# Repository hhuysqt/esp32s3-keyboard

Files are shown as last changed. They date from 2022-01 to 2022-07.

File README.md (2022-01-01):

# Thinkpad USB/BLE keyboard based on ESP32S3

This USB/BLE keyboard controller is built upon ESP32S3 (the ESP32S3-WROOM-1 module), which has hardware USB & BLE peripherals. It can support multiple Thinkpad laptop keyboards, if not limited to all sorts of matrix keyboards. The following functions are supported:

- Keyboard & LED;
- Mouse (trackpoint);
- Fn consumer/multimedia keys;
- USB & BLE connection;
- "Low-power": around 6-day BLE connection on a 1500mAh battery;

Tested on T440/T470/E430/E530/E580.

- E580 keyboard with 3D printed case:
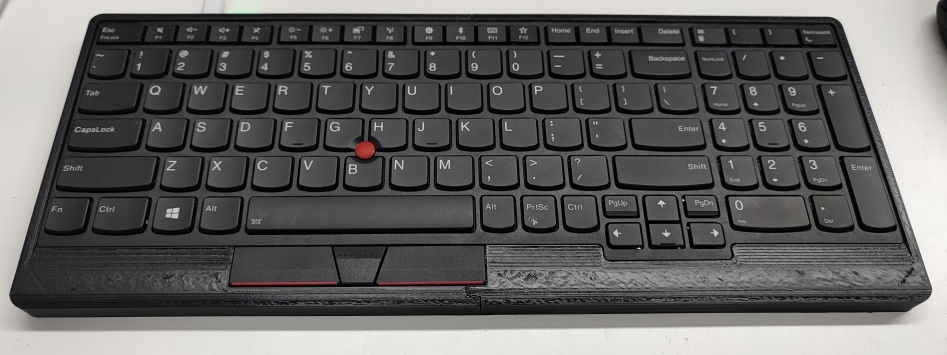
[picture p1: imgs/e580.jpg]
E580


- T470/T480 keyboard:
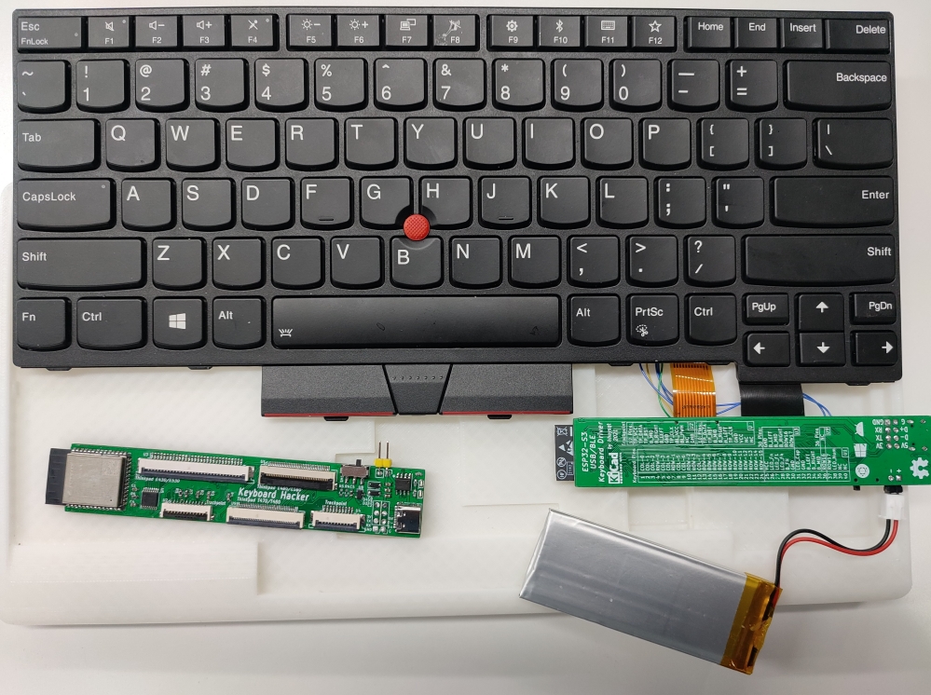
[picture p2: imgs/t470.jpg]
T470


The BLE and USB driver is mainly modified from:
- [ble_hid_device_demo](https://github.com/espressif/esp-idf/tree/master/examples/bluetooth/bluedroid/ble/ble_hid_device_demo) in `esp-idf`;
- [tinyusb hid](https://github.com/iot-components/tinyusb.git) component addon;

## Hardware

The Thinkpad keyboard modules are similar. Usually it contains a 32-40 pins FPC cable for keyboard matrix and LEDs, and a 10-12 FPC cable for trackpoint, mouse buttons and backlight. The keyboard matrix comprises 24 or 26 pins, where 8 of them are sense ports and the remaining drive ports. The trackpoint contains 3 input ports for mouse buttons, and a PS2 interface for mouse report. The following pinout is extracted from the [E580](https://badcaps.net/forum/attachment.php?attachmentid=215193&d=1593808132) schematic.

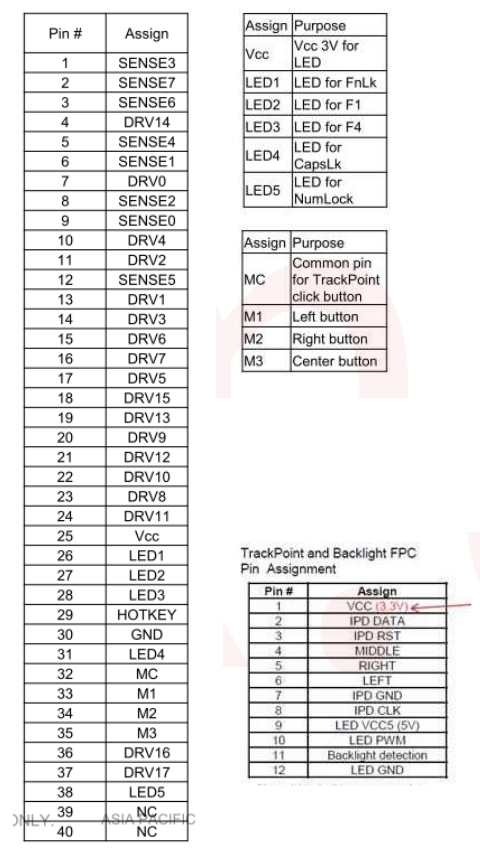
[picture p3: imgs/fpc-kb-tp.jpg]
Keyboard & trackpoint pinout


Although ESP32 has no PS2 interface, we notice that the slave-to-host timing of PS2 DATA pin is identical to the UART (1 start bit, 8 data bit, 1 odd parity, 1 stop bit). While by contrast the host-to-slave timing is NOT compatible, this only happens during initialization. Thereby this step requires bit-banging.

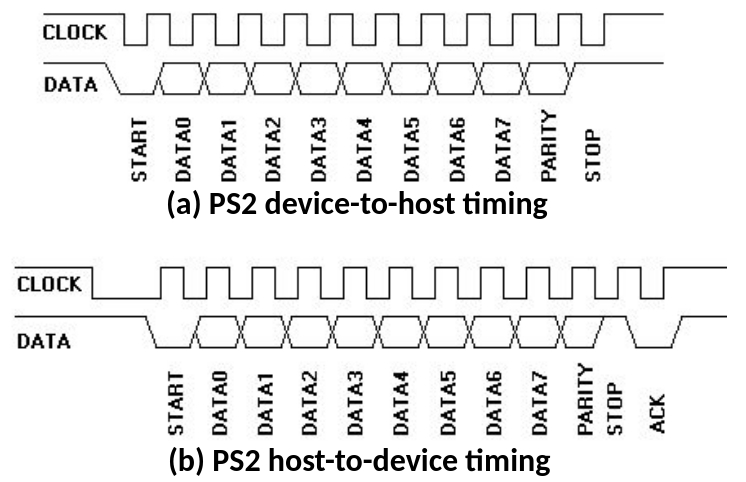
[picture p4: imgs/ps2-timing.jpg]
PS2 timing


The ESP32S3-WROOM-1 module has 36 GPIOs, among which should reserve the USB port (IO19/20), and the 32.768kHz external oscillator for low-power modem sleep (IO15/16). To fully drive the keyboard matrix, LEDs and PS2 trackpoint mouse, a 74HC138 is used to expand the poor IOs... See the [schematic](hardware/esp32_keyboard.pdf) for detail.
- Keyboard: 3 pins for column scanning with 74HC138, plus 18 pins for row sensing;
- Trackpoint: 3 pins (RST, CLK, DATA);
- LEDs: 4 pins (FnLock, CapLk, NumLk, F1, mux with the UART0), plus 1 pin for the keyboard backlight;
- Hotkey/Fn: 1 pin;
- 5V wake up: 1 pin;
- Download Pin: IO0, connected to the middle button;

## Build & Run

We build with the normal esp-idf project workflow on Linux:

```bash
idf.py set-target esp32s3
idf.py build
```

To update the firmware, we should first power off the board, hold the middle button, plug in the USB cable, and then we can release the button. The USB-CDC hardware in the ESP32S3 should launch a `/dev/ttyACMx` on your computer, which can be used to flash the firmware:

``` bash
idf.py -p /dev/ttyACM0 flash
```

Finally, unplug the USB cable and power on the board.

## Power consumption

The ESP32 is known to be power hungry... We use a 1500mAH battery for the keyboard, and the original `ble_hid_device_demo` would take over 100mA without midification, which means a poor 15-hour battery life. For lower-power design, we should adopt the [BLE modem sleep with external 32kHz crystal under light sleep](https://github.com/espressif/esp-idf/issues/947#issuecomment-500312453), which claims an average ~2mA current with ~1000ms BLE connection interval. However, 1000ms (1Hz) interval is too long for real-time keyboard response, and we have to decrease it to around 50ms (20Hz) for normal use. Moreover, the trackpoint/mouse requires a even shorter period, which we set to 12.5ms (80Hz). With this backdrop, we develop a multi-stage power management as follow. This can be configured in [keyboard_pm.c](main/keyboard_pm.c).

| Charging | BLE Connect | Keyboard Scanning | Trackpoint | BLE Interval | Current | Duration |
|--|--|--|--|--|--|--|
| No | No | Slow | No | 1000ms | ~5mA | - |
| No | Yes | Slow | No | 1000ms | ~8mA | - |
| No | Yes | Slow | No | 400ms | 13mA | 120s |
| No | Yes | Fast | No | 50ms | 30mA | 240s |
| No | Yes | Fast | Yes (cannot sleep) | 12.5ms | 53mA | 120s |
| Yes | - | - | - | - | -500mA | - |

Note:
- The ESP32 light sleep would force turning off all the peripherals, which means that we will never receive trackpoint message at sleep. So the trackpoint forces no sleep.
- The USB 2.0 host could offer ~500mA current, which means that it takes 3 hours to charge the 1500mAh battery. This is quite a modest setting, and this is why we don't use a larger battery like 2500mAh.
- Backlight takes an additional 50mA.

Battery life estimation (1500mAh):
- 12 days if no BLE connection;
- ~6 days for normal use;

## TODO list

- Online configuration;
- `Fn` and `Left Ctrl` exchange;
- Multiple BLE cnnection;
- More keyboards, e.g. X220;
- More OS support, e.g. Mac;

## Reference

- [How to Make a USB Laptop Keyboard Controller](https://www.instructables.com/How-to-Make-a-USB-Laptop-Keyboard-Controller/)
- [Laptop Touchpad/Trackpoint Conversion to USB](https://www.hackster.io/frank-adams/laptop-touchpad-trackpoint-conversion-to-usb-d70519)
- [esp32 BLE bridge for mouse and keyboard](https://github.com/asterics/esp32_mouse_keyboard)
- [HID scancodes](https://deskthority.net/wiki/Scancode#cite_ref-xmeta_13-0)
- [Trackpoint hardware](https://deskthority.net/wiki/TrackPoint_Hardware)

Thinkpad schematics:
- [T440](https://drive.google.com/file/d/1L-NCRwoP0IHYmOoxbS2U5ZWHYhyHf4xC/view)
- [T470](https://www.badcaps.net/forum/attachment.php?attachmentid=201515&d=1571565529)
- [E430/E530](https://drive.google.com/file/d/0B6IqcVTk0jpYV0xfMUdOay1uWlE/view?resourcekey=0-oamnnXMgSrohielovUks4A)
- [E580](https://badcaps.net/forum/attachment.php?attachmentid=215193&d=1593808132)

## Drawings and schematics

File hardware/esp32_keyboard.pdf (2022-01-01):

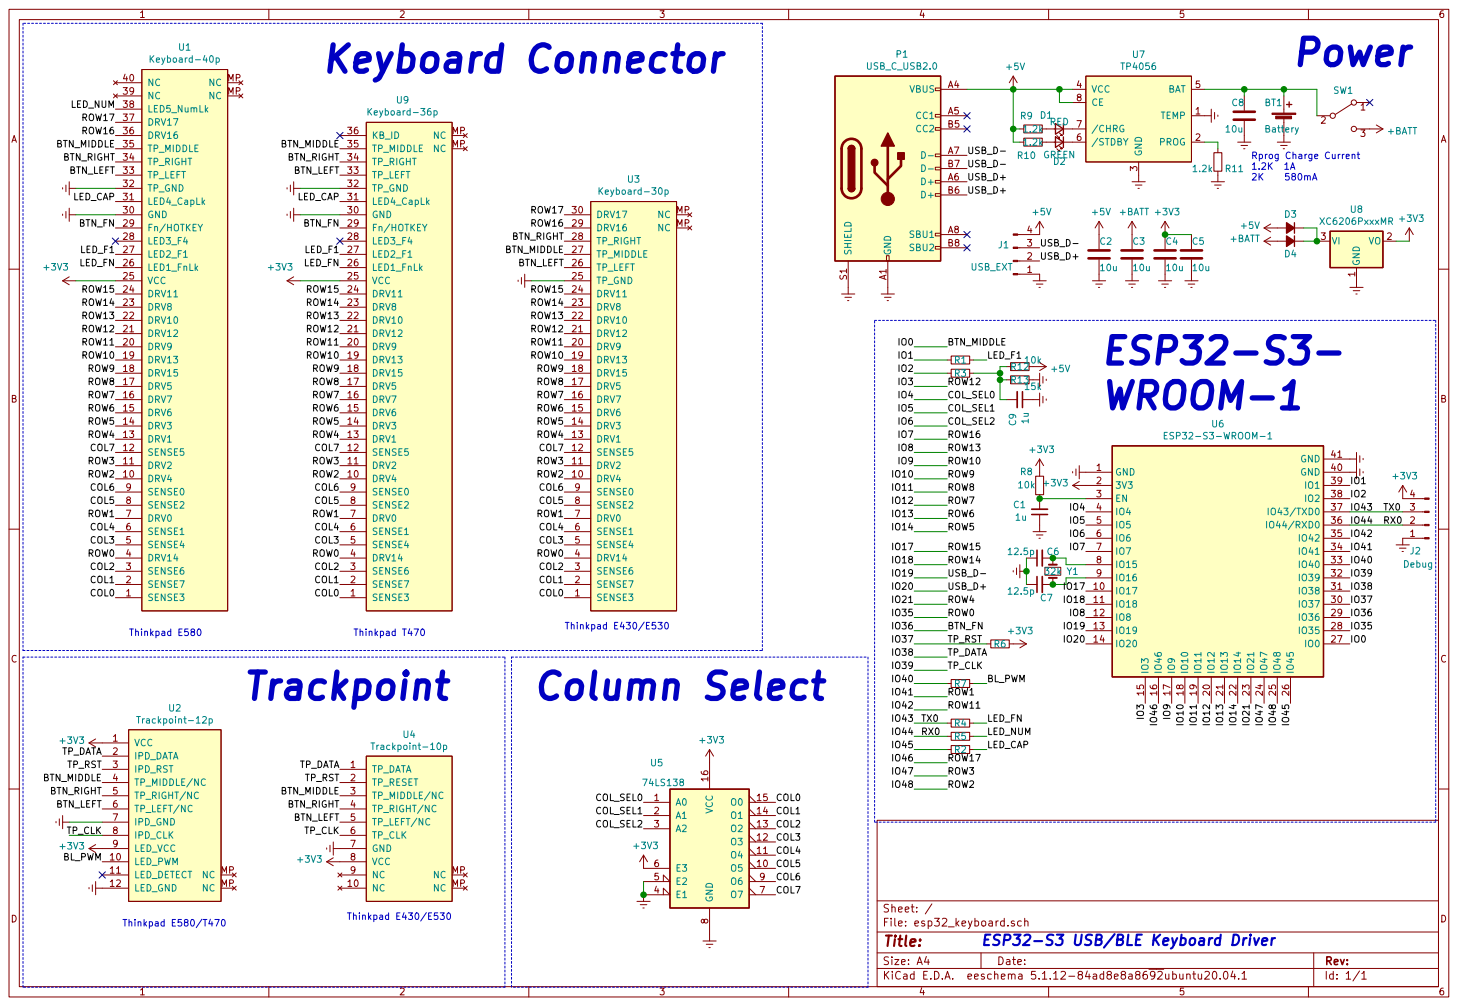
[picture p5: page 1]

BTN_LEFT ROW15 ROW14 ROW13 ROW12 ROW11 ROW10 ROW9
2K 580mA ESP32-S3 USB/BLE Keyboard Driver

1 VO 2 VI 3 U8 XC6206PxxxMR GND A1 VBUS A4 CC1 A5 D+ A6 D- A7 SBU1 A8 CC2 B5 D+ B6 D- B7 SBU2 B8 SHIELD S1 P1 USB_C_USB2.0 R3 R7 +3V3 C91u R5 R2

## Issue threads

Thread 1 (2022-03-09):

关注 X220 键盘适配

M69W, 2022-03-09:
目前使用 X220 键盘，手感略好。
大佬们，有任何进展或 建议，
不妨在这里，我们一起讨论交流？

hhuysqt, 2022-03-09:
x220的板对板接口，集合了矩阵键盘和小红点ps2接口，这份代码应该都能驱动起来，按理说加一个转接板就好了。

GaloisTsai, 2022-03-23:
> 目前使用 X220 键盘，手感略好。 大佬们，有任何进展或 建议， 不妨在这里，我们一起讨论交流？

[淘宝xy3dg12的小店](https://xy3dg12.taobao.com/)2年前曾经做过x220键盘的三模驱动板但不幸的是已停产，[Hearttolin工作室](https://jiushuma.taobao.com/)也有拿STM32做的有线版目前还在售，两者我都有

M69W, 2022-03-24:
> > 目前使用 X220 键盘，手感略好。 大佬们，有任何进展或 建议， 不妨在这里，我们一起讨论交流？
>
> [淘宝xy3dg12的小店](https://xy3dg12.taobao.com/)2年前曾经做过x220键盘的三模驱动板但不幸的是已停产，[Hearttolin工作室](https://jiushuma.taobao.com/)也有拿STM32做的有线版目前还在售，两者我都有

他们的 2 模、3模，我也要。
这里大佬的，我也买了。

不太想为了键盘体验而去买几千元整机。

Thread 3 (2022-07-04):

准备搞个X200的，请教作者几个问题

hktklsh, 2022-07-04:
首先感谢作者的分享，家里有个x200的闲置键盘，准备搞一搞，有几个问题想请教下作者：
1、由于鼠标中键没有对应引脚，把power按键接IO0可行不，或者您有什么更好的建议吗？
2、keymap如何映射，每按一个键，调试口会输出按键map信息吗？
3、x200键盘上没有指示灯，需要单独接led，对于驱动指示灯的引脚，我应该接led的正还是负？

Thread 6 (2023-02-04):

Any way to buy the board outside China?

diyprojectz, 2023-02-04:
Hello,

Is there any way I can order it? I am outside China.

Thank you

你好，

有什么办法可以订购吗？ 我在中国境外。

谢谢

hhuysqt, 2023-02-06:
Hi, I've updated the kicad PCB project along with gerber files, so that you can make the PCB on your own. Sorry but I'm no longer selling the board since it is just a hobby project :-D

antonba, 2025-09-17:
What is a good company to order the board from that can also solder all components on it (e.g. ESP32, FPC connectors, USB connetors)? Which company did you use?

Closed 2023-02-06.

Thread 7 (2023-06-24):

fpc插座要用怎样的？

lantianning, 2023-06-24:
我按照电路图要求先找了一块T470键盘，然后找了2块fpc插座，一个是36P 0.5mm间距，另外一个是12P 1mm间距的，结果把键盘插上去，发现卡不住，总觉得差哪里？不知道插座的厚度有没有要求？究竟这个fpc插座的规格？还有什么细节要求？求大神指导。

hhuysqt, 2023-06-25:
卡扣也占地方的，我试验用40pin 0.5的刚好安装，前后预留两个空脚。12pin的要带卡扣的，我买了这个能用，具体型号不清楚。
【淘宝】https://m.tb.cn/h.UA6Ymtd?tk=IRE0dINBQKo CZ3457 「FPC连接器12P翻盖式下接1.0MM间距 12PIN带定位卡扣软排线FFC插座」
点击链接直接打开 或者 淘宝搜索直接打开

lantianning, 2023-07-04:
谢谢你，我先记录了

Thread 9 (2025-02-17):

Do you plan on makeing 220 or 60 series version?

Onshumikan, 2025-02-17:
Hi, I have a broken x61, and wanted to make a usb & Bluetooth keyboard from it.
After searching around, I found your project.
Since, I saw other issues talking about x220? (sorry if im wrong, i could only read the "x220") , 60 series keyboard connector(AA01B-S040VA1) is simillar to x220s and you had it in your TO DO list, i wondered if you were already working on it.

If not, i was thinking of trying to make one my self, and i wanted an advice on how to make it.

i found several people who made an usb controller but not one with a bluetooth function.
https://github.com/xing2387/esp32s3_tpkb
https://github.com/thedalles77/USB_Laptop_Keyboard_Controller/tree/master/Example_Keyboards/Pico_T61_Keyboard

thanks to their work, they made a list of pinout for the 60 series keyboard connector(AA01B-S040VA1).
which, made me wonder if i can make one by modifying your design to match the connector pins.

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

however, im not that sure about which pins match which GPIOS.

can you help me out with it?

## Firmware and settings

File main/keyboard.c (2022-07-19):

/**
 * This file is part of esp32s3-keyboard.
 *
 * Copyright (C) 2020-2021 Yuquan He <heyuquan20b at ict dot ac dot cn> 
 * (Institute of Computing Technology, Chinese Academy of Sciences)
 *
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
 * You should have received a copy of the GNU General Public License
 * along with esp32s3-keyboard. If not, see <http://www.gnu.org/licenses/>.
 */

/**
 * Driver for Thinkpad keyboard & trackpad
 * USB & BLE interface.
 */

#include <stdio.h>
#include <string.h>
#include "freertos/FreeRTOS.h"
#include "freertos/task.h"
#include "sdkconfig.h"
#include "esp_log.h"

#include "driver/gpio.h"
#include "driver/uart.h"

#include "tusb.h"
#include "tusb_hid.h"
#include "tinyusb.h"
#include "esp_hidd_prf_api.h"
#include "esp_gap_ble_api.h"

#include "keymap.h"

#include "esp_err.h"
#include "esp_pm.h"
#include "esp_sleep.h"
#include "esp_timer.h"

#include <sys/fcntl.h>
#include <sys/errno.h>
#include <sys/unistd.h>
#include <sys/select.h>

#include "pin_cfg.h"
#include "keyboard_pm.h"

/****************************************************************
 * 
 *  Private Definition
 * 
 ****************************************************************/

// #define USE_FN_TRACKPOINT_PAN
#define SCALE_TRACKPOINT_SPEED
#define MOUSE_SCALE_MIN 1

/****************************************************************
 * 
 *  Private Varibles
 * 
 ****************************************************************/

static bool is_init_finish = false;
static bool is_fn_locked = 0;

// keyboard pin array
static uint rowscan_pins[18] = {
  KB_ROW_0, KB_ROW_1, KB_ROW_2, KB_ROW_3, KB_ROW_4, KB_ROW_5, KB_ROW_6, KB_ROW_7,
  KB_ROW_8, KB_ROW_9, KB_ROW_10, KB_ROW_11, KB_ROW_12, KB_ROW_13, KB_ROW_14, KB_ROW_15,
  KB_ROW_16, KB_ROW_17,
};

// UART1 fd for select()
static int uart1_fd = -1;

static uint wakeup_time = 0;
static const uint wakeup_period_us = 15000000;

// backlight duration
static const int MAX_BACKLIGHT_ON_US = 10*60*1000000;

static const char *TAG = "kb-task";

/****************************************************************
 * 
 *  Public Varibles
 * 
 ****************************************************************/

volatile bool is_usb_connected = false;
volatile bool is_backlight_on = false;
volatile int backlight_start_time;

// Manage LED state since Win10 won't report such info on BLE.
volatile bool is_caplk_on = false;
volatile bool is_numlk_on = false;

// bluetooth stuff
extern bool is_ble_connected;
extern esp_ble_conn_update_params_t ble_conn_param;
extern esp_pm_config_esp32s3_t esp_idf_pm_cfg;

/****************************************************************
 * 
 *  Private function prototypes
 * 
 ****************************************************************/

static void ps2_gpio_init(void);
static uint8_t ps2_read(void);
static void ps2_write_1(uint8_t ch);
static void ps2_write_2(uint8_t ch);

static void init_usb(void);
static void init_trackpad(void);
static void init_matrix_keyboard(void);

static void kb_set_column_scan(int n);
static void do_fnfunc(fn_function_t fncode);
static void led_task(void *arg);
static void poll_trackpoint(uint poll_ms);

/****************************************************************
 * 
 *  Callback override
 * 
 ****************************************************************/

// tinyusb callbacks for connection
void tud_mount_cb(void)
{
  is_usb_connected = true;
  printf("USB connected.\n");
  if (is_init_finish) {
    flush_power_state(PM_CHARGING);
  }
}

// tinyusb callbacks for disconnection
void tud_umount_cb(void)
{
  is_usb_connected = false;
  printf("USB disconnected\n");
}

void tud_suspend_cb(bool remote_wakeup_en)
{
  (void)remote_wakeup_en;
  is_usb_connected = false;
  // printf("USB suspended, %s\n");
  printf("%s(%s)\n", __func__, remote_wakeup_en ? "true" : "false");
}

void tud_resume_cb(void)
{
  is_usb_connected = true;
  printf("%s\n", __func__);
  if (is_init_finish) {
    flush_power_state(PM_CHARGING);
  }
}

void kb_led_cb(uint8_t kbd_leds)
{
  if (kbd_leds & KEYBOARD_LED_NUMLOCK) {
    LED_NUMLK_ON;
    is_numlk_on = true;
  } else {
    LED_NUMLK_OFF;
    is_numlk_on = false;
  }

  if (kbd_leds & KEYBOARD_LED_CAPSLOCK) {
    // Sometimes the GPIO may be reset on wake-up...
    // Manually init it again...
    GPIO_INIT_OUT_PULLUP(LED_CAPLK);
    LED_CAPLK_ON;
    is_caplk_on = true;
  } else {
    LED_CAPLK_OFF;
    is_caplk_on = false;
  }
}


/****************************************************************
 * 
 *  Private functions
 * 
 ****************************************************************/

/**
 * Initialize trackpad GPIO
 */
static void ps2_gpio_init(void)
{
  GPIO_INIT_OUT_PULLUP(PS2_CLK_PIN);
  GPIO_INIT_OUT_PULLUP(PS2_DATA_PIN);
  PS2_CLK_HIGH;
  PS2_DATA_HIGH;
}
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

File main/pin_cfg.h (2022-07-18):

/**
 * This file is part of esp32s3-keyboard.
 *
 * Copyright (C) 2020-2021 Yuquan He <heyuquan20b at ict dot ac dot cn> 
 * (Institute of Computing Technology, Chinese Academy of Sciences)
 *
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
 * You should have received a copy of the GNU General Public License
 * along with esp32s3-keyboard. If not, see <http://www.gnu.org/licenses/>.
 */

/**
 * Keyboard pin configuration
 */
#ifndef MY_PIN_CFG_H
#define MY_PIN_CFG_H

#include "sdkconfig.h"
#include "driver/gpio.h"


/****************************************************************
 * 
 *  GPIO allocation
 * 
 ****************************************************************/

// 8 column scan with 74HC138
#define KB_COLSEL_0   4
#define KB_COLSEL_1   5
#define KB_COLSEL_2   6

// 18 row scan
#define KB_ROW_0      35
#define KB_ROW_1      41
#define KB_ROW_2      48
#define KB_ROW_3      47
#define KB_ROW_4      21
#define KB_ROW_5      14
#define KB_ROW_6      13
#define KB_ROW_7      12
#define KB_ROW_8      11
#define KB_ROW_9      10
#define KB_ROW_10     9
#define KB_ROW_11     42
#define KB_ROW_12     3
#define KB_ROW_13     8
#define KB_ROW_14     18
#define KB_ROW_15     17
#define KB_ROW_16     7
#define KB_ROW_17     46

// Buttons
#define BUTTON_MIDDLE 0
#define BUTTON_FN     36

// LED
#define LED_CAPLK     45
#define LED_FNLK      43
#define LED_F1        1
#define LED_NUMLK     44
#define BACKLIGHT_PWM 40
// #define LED_F4        7

// Trackpad GPIO
#define PS2_CLK_PIN     39
#define PS2_DATA_PIN    38
#define PS2_RESET_PIN   37

// USB charging detection
#define CHARGING_PIN    2

#define BUTTON_MIDDLE_STATE gpio_get_level(BUTTON_MIDDLE)
#define BUTTON_FN_STATE     gpio_get_level(BUTTON_FN)

#define LED_CAPLK_ON    gpio_set_level(LED_CAPLK, 0)
#define LED_CAPLK_OFF   gpio_set_level(LED_CAPLK, 1)
#define LED_FNLK_ON     gpio_set_level(LED_FNLK, 0)
#define LED_FNLK_OFF    gpio_set_level(LED_FNLK, 1)
#define LED_F1_ON       gpio_set_level(LED_F1, 0)
#define LED_F1_OFF      gpio_set_level(LED_F1, 1)
#define LED_NUMLK_ON    gpio_set_level(LED_NUMLK, 0)
#define LED_NUMLK_OFF   gpio_set_level(LED_NUMLK, 1)
#define BACKLIGHT_ON    gpio_set_level(BACKLIGHT_PWM, 1)
#define BACKLIGHT_OFF   gpio_set_level(BACKLIGHT_PWM, 0)
// #define LED_F4_ON       gpio_set_level(LED_F4, 0)
// #define LED_F4_OFF      gpio_set_level(LED_F4, 1)

#define PS2_CLK_STATE   gpio_get_level(PS2_CLK_PIN)
#define PS2_CLK_OUTPUT  gpio_set_direction(PS2_CLK_PIN,  GPIO_MODE_OUTPUT)
#define PS2_CLK_INPUT   gpio_set_direction(PS2_CLK_PIN,  GPIO_MODE_INPUT)
#define PS2_CLK_LOW     gpio_set_level(PS2_CLK_PIN, 0)
#define PS2_CLK_HIGH    gpio_set_level(PS2_CLK_PIN, 1)
#define PS2_DATA_STATE  gpio_get_level(PS2_DATA_PIN)
#define PS2_DATA_OUTPUT gpio_set_direction(PS2_DATA_PIN, GPIO_MODE_OUTPUT)
#define PS2_DATA_INPUT  gpio_set_direction(PS2_DATA_PIN, GPIO_MODE_INPUT)
#define PS2_DATA_LOW    gpio_set_level(PS2_DATA_PIN, 0)
#define PS2_DATA_HIGH   gpio_set_level(PS2_DATA_PIN, 1)

#define CHARGING_STATE  gpio_get_level(CHARGING_PIN)

/****************************************************************
 * 
 *  Handy GPIO helpers
 * 
 ****************************************************************/

#define GPIO_INIT_IN_FLOATING(pinnum) \
  do { \
    gpio_reset_pin(pinnum); \
    gpio_set_direction(pinnum, GPIO_MODE_INPUT); \
    gpio_pullup_dis(pinnum); \
    gpio_pulldown_dis(pinnum); \
  } while(0)

#define GPIO_INIT_IN_PULLUP(pinnum) \
  do { \
    gpio_reset_pin(pinnum); \
    gpio_set_direction(pinnum, GPIO_MODE_INPUT); \
    gpio_pullup_en(pinnum); \
    gpio_pulldown_dis(pinnum); \
  } while(0)

#define GPIO_INIT_IN_PULLDOWN(pinnum) \
  do { \
    gpio_reset_pin(pinnum); \
    gpio_set_direction(pinnum, GPIO_MODE_INPUT); \
    gpio_pullup_dis(pinnum); \
    gpio_pulldown_en(pinnum); \
  } while(0)

#define GPIO_SET_PULLUP(pinnum) \
  do { \
    gpio_pullup_en(pinnum); \
    gpio_pulldown_dis(pinnum); \
  } while(0)

#define GPIO_SET_PULLDOWN(pinnum) \
  do { \
    gpio_pullup_dis(pinnum); \
    gpio_pulldown_en(pinnum); \
  } while(0)

#define GPIO_INIT_OUT_PULLUP(pinnum) \
  do { \
    gpio_reset_pin(pinnum); \
    gpio_set_direction(pinnum, GPIO_MODE_OUTPUT); \
    gpio_pullup_en(pinnum); \
  } while(0)

#define GPIO_INIT_OUT_PULLDOWN(pinnum) \
  do { \
    gpio_reset_pin(pinnum); \
    gpio_set_direction(pinnum, GPIO_MODE_OUTPUT); \
    gpio_pulldown_en(pinnum); \
  } while(0)

#endif

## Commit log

2022-01-13 Enable Numlk LED (disable UART) and adjust power settings a little bit
2022-04-04 Add RESOLUTION_MULTIPLIER feature for high-resolution pointer & wheel
2022-07-18 Fix compilation with the latest esp-idf and components
    - Replace `gpio_pad_select_gpio` with `gpio_reset_pin`, refering to
    https://www.esp32.com/viewtopic.php?t=25505
    - `xQueueHandle` is no longer defined if
    `CONFIG_FREERTOS_ENABLE_BACKWARD_COMPATIBILITY` is not set
    - Remove variable `tusb_desc_set` which prevents compilation and is never used
    - Include `rom/gpio.h` for macro `GPIO_FUNC_IN_LOW` and `GPIO_FUNC_IN_HIGH`
    [keyboard_pm.c, pin_cfg.h, tinyusb.c]
2023-02-06 Add kicad PCB project
    [esp32_keyboard-v0.1.kicad_pcb, esp32_keyboard-v0.1.sch]

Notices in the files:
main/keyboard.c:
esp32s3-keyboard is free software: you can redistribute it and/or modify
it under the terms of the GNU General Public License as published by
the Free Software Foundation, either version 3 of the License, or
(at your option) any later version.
